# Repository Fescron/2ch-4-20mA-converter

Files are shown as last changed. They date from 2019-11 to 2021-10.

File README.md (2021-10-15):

# 2ch-4-20mA-converter






<br/>

This board converts two *4 - 20 mA* signals to a voltage using a `LMP8640` *Current Shunt Monitor* from *Texas Instruments*. To provide power to the *4 - 20 mA* sensors a `TEC2-0913` 2W 15V Isolated DC-DC converter is used from *Traco Power*. Quick-connect terminals from *Phoenix Contact* are also used.

To allow for extensive testing three separate GND nets/planes and a lot of test points are used. They can be connected together using jumpers if necessary. The power supply can also be disabled and fully disconnected from the sensors using a jumper as well (wich can also be used to measure the in-line current given to the whole sensor circuit).

- Click [here](hardware/2ch-4-20mA/2ch-4-20mA.pdf) to go to the **schematic**.

<br/>

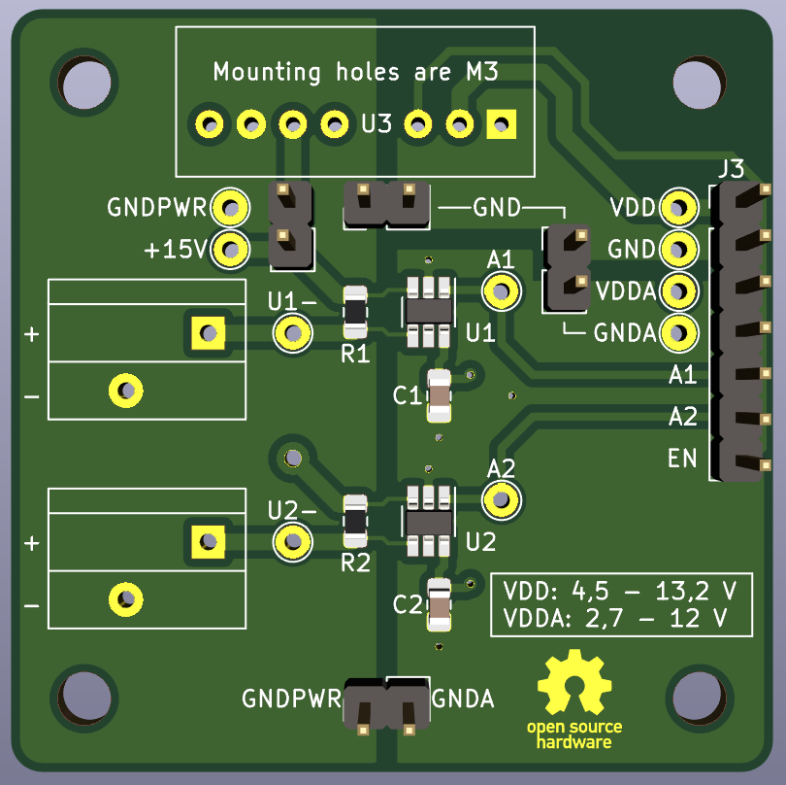
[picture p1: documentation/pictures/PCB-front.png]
PCB front
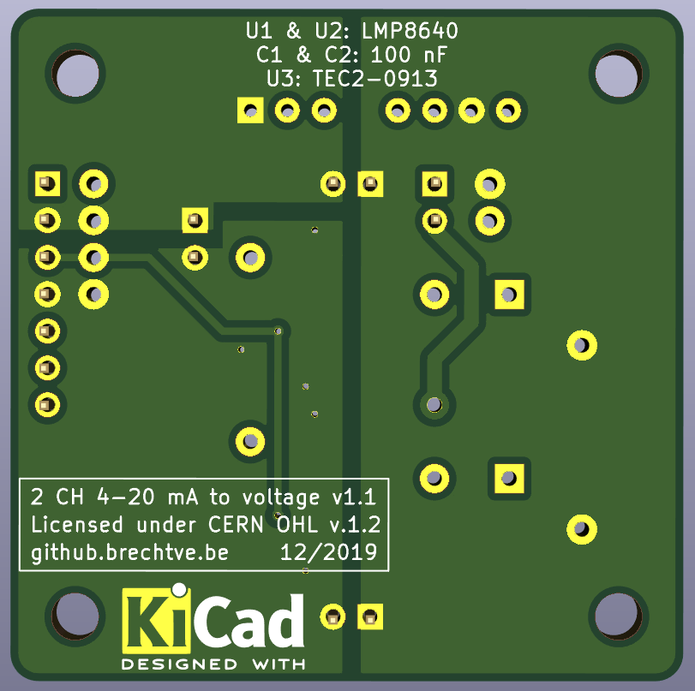
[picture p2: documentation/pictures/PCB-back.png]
PCB back
 &nbsp; &nbsp; &nbsp; &nbsp; &nbsp; 

<br/>

## LMP8640 vs INA196

A lot of designs still use the `INA196` *Current Shunt Monitor* from *Texas Instruments*. In the picture below is a comparison between the `LMP8640` and the `INA196`. No real disadvantage was found to not use the `LMP8640`.

<br/>

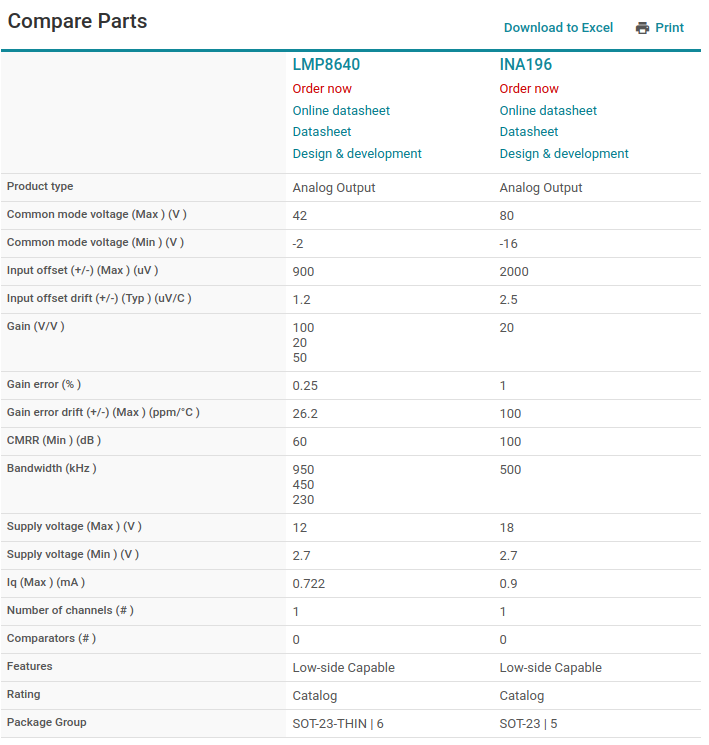
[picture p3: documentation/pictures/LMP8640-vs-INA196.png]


<br/>

## BOM

| Component | Value | Footprint | Other | Ordering |
| --- | --- | --- | --- | --- |
| U1, U2 | LMP8640 | SOT-23-Thin-6 | Texas Instruments Current Shunt Monitor | [Mouser.be](https://www.mouser.be/ProductDetail/Texas-Instruments/LMP8640MK-T-NOPB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) |
| U3 | TEC2-0913 | SIP-8 | Traco Power 2W 15V Isolated DC-DC converter | [Mouser.be](https://www.mouser.be/ProductDetail/TRACO-Power/TEC-2-0913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) |
| C1, C2 | 100 nF = 0,1 µF | 0805 | X7R, 16V, 10% | [Mouser.be](https://www.mouser.be/ProductDetail/Yageo/CC0805KRX7R7BB104?qs=sGAEpiMZZMs0AnBnWHyRQMMzfhmH8IQX2eB5GrOHrwc%3D) |
| R1, R2 | 6,2 Ω | 0805 | 0,1% | [Mouser.be](https://www.mouser.be/ProductDetail/TE-Connectivity-Neohm/CPF0805B6R2E1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) |
| R1, R2 (alt) | 4,99 Ω | 0805 | 0,1% | [Mouser.be](https://www.mouser.be/ProductDetail/TE-Connectivity-Neohm/CPF0805B4R99E1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) |
| J1, J2 | PTSA_1,5/_2-3,5-Z_BK | Pitch: 3,5 mm | 2 contacts @ 45° (20-16 AWG), 250V 2A | [Mouser.be](https://www.mouser.be/ProductDetail/Phoenix-Contact/1751765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) |

<br/>

## UPDATE 03/2020 - 1 CH board without power supply

To better conduct tests with the `LMP8640` chip a simple 1-CH board was layed out without a power supply and etched on a single sided board.

- Click [here](hardware/1ch-4-20mA/Plots/1ch-4-20mA.pdf) to go to the **schematic**.
- Click [here](hardware/1ch-4-20mA/Plots/1ch-4-20mA-F_Cu.pdf) to go to the **board layout** (mirrored).

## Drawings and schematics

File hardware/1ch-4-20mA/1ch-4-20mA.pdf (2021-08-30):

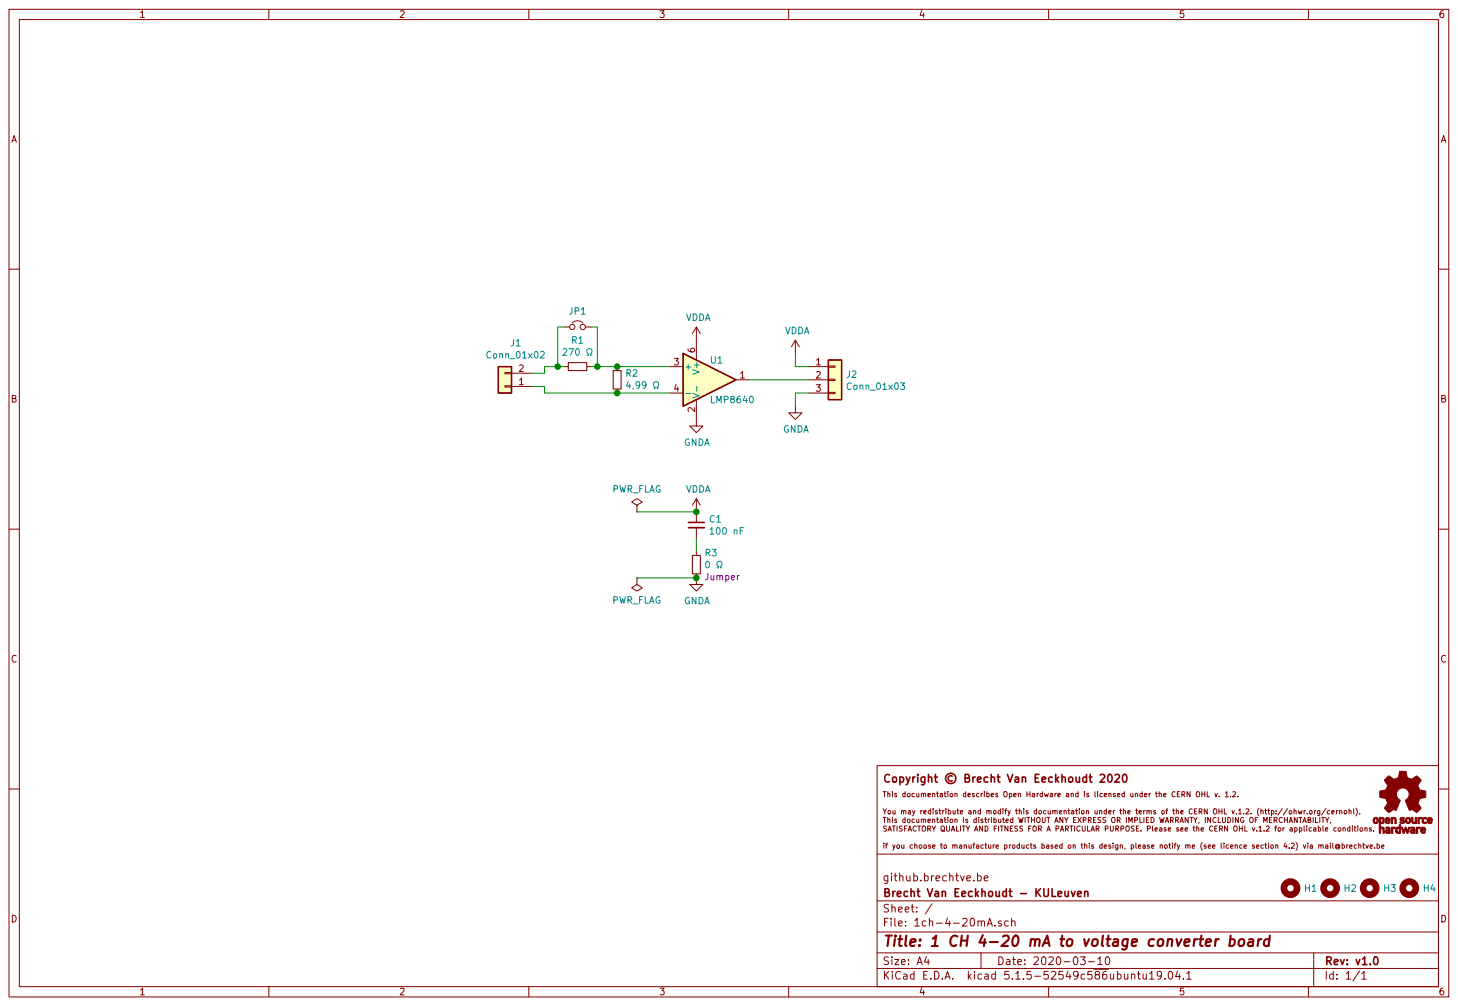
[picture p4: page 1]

Copyright © Brecht Van Eeckhoudt 2020

This documentation describes Open Hardware and is licensed under the CERN OHL v. 1.2.

You may redistribute and modify this documentation under the terms of the CERN OHL v.1.2. (http://ohwr.org/cernohl).

if you choose to manufacture products based on this design, please notify me (see licence section 4.2) via mail@brechtve.be H2

github.brechtve.be
File: 1ch-4-20mA.sch Sheet: / Brecht Van Eeckhoudt - KULeuven

Id: 1/1 Title: 1 CH 4-20 mA to voltage converter board

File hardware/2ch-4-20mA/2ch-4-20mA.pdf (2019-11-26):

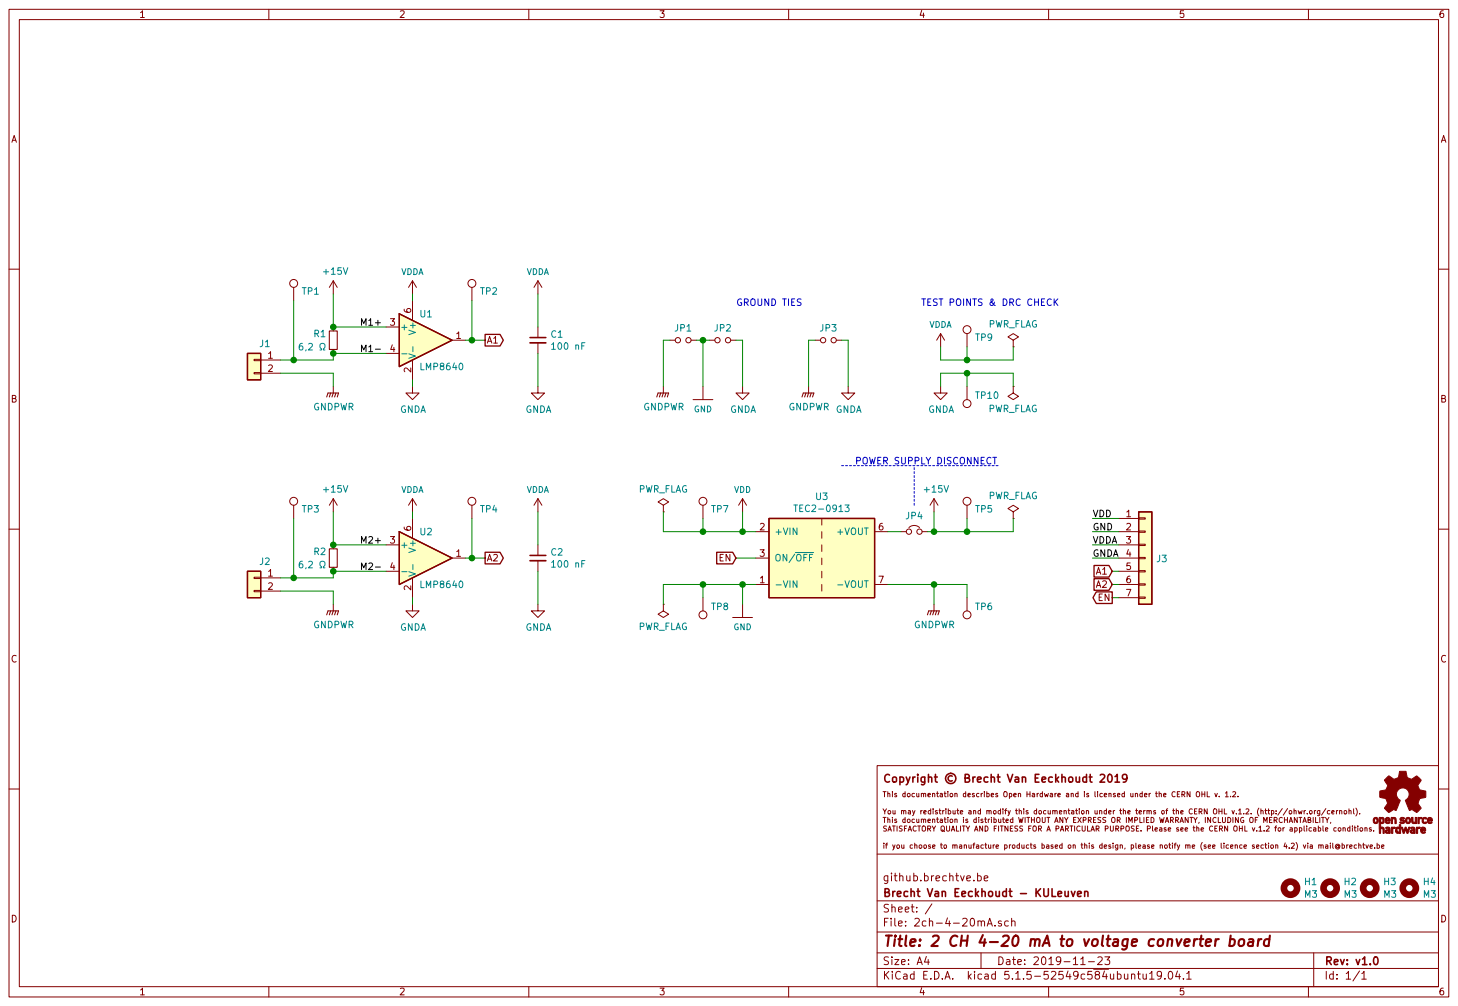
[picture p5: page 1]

TEST POINTS & DRC CHECK

Copyright © Brecht Van Eeckhoudt 2019

This documentation describes Open Hardware and is licensed under the CERN OHL v. 1.2.

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

github.brechtve.be
File: 2ch-4-20mA.sch Sheet: / Brecht Van Eeckhoudt - KULeuven

Id: 1/1 Title: 2 CH 4-20 mA to voltage converter board

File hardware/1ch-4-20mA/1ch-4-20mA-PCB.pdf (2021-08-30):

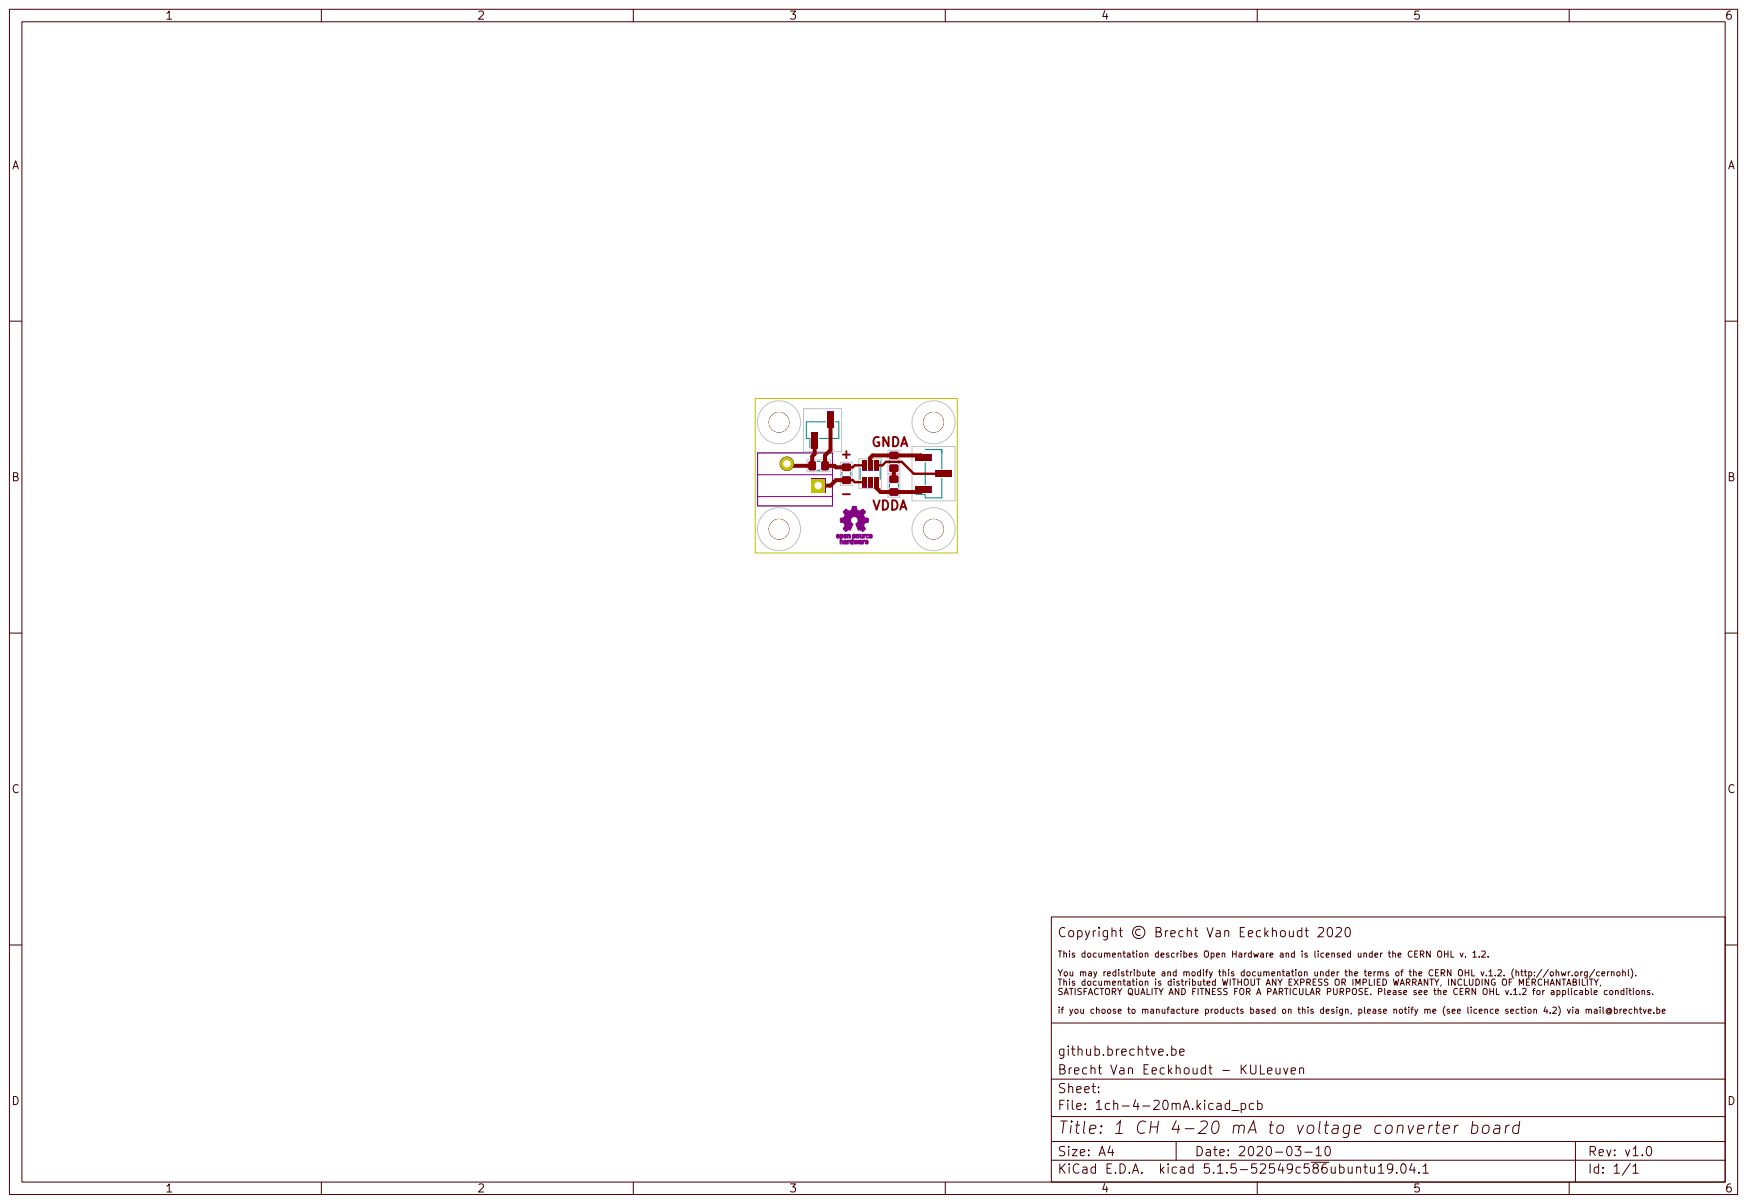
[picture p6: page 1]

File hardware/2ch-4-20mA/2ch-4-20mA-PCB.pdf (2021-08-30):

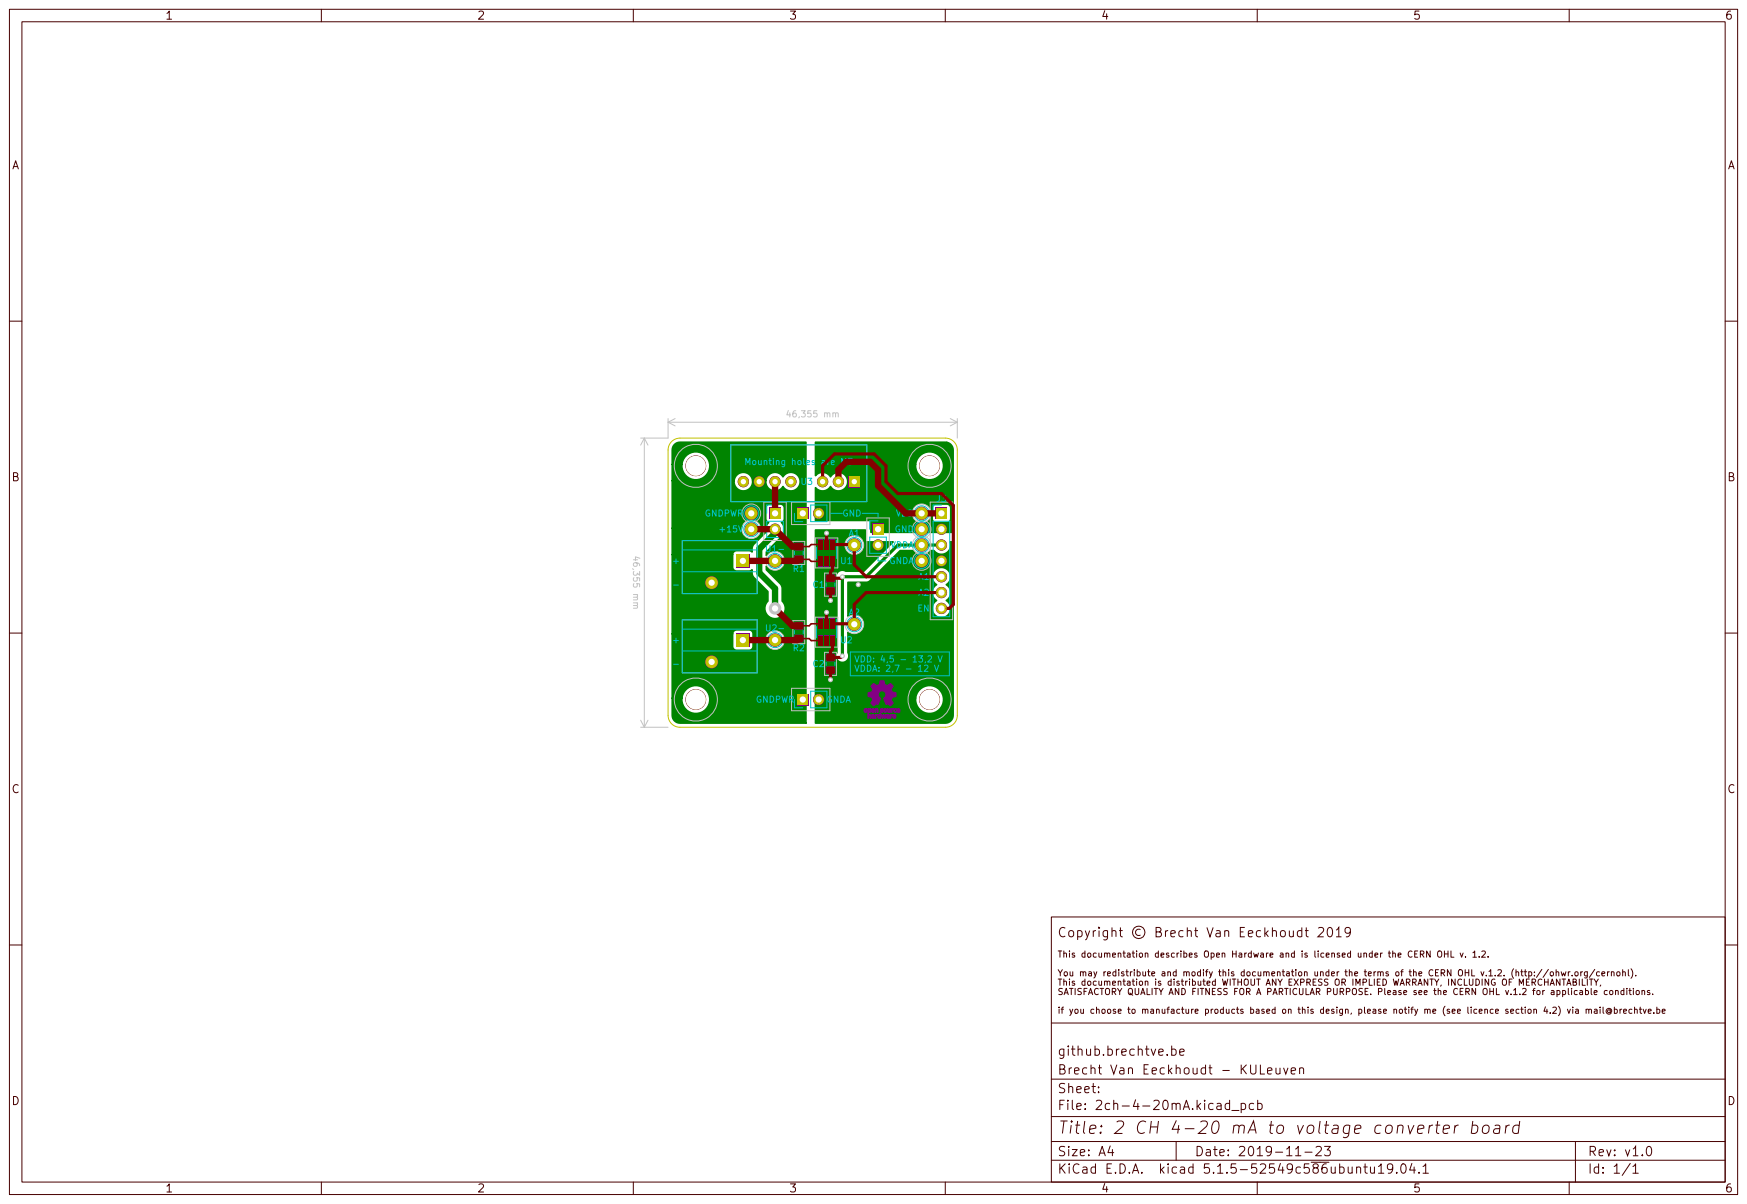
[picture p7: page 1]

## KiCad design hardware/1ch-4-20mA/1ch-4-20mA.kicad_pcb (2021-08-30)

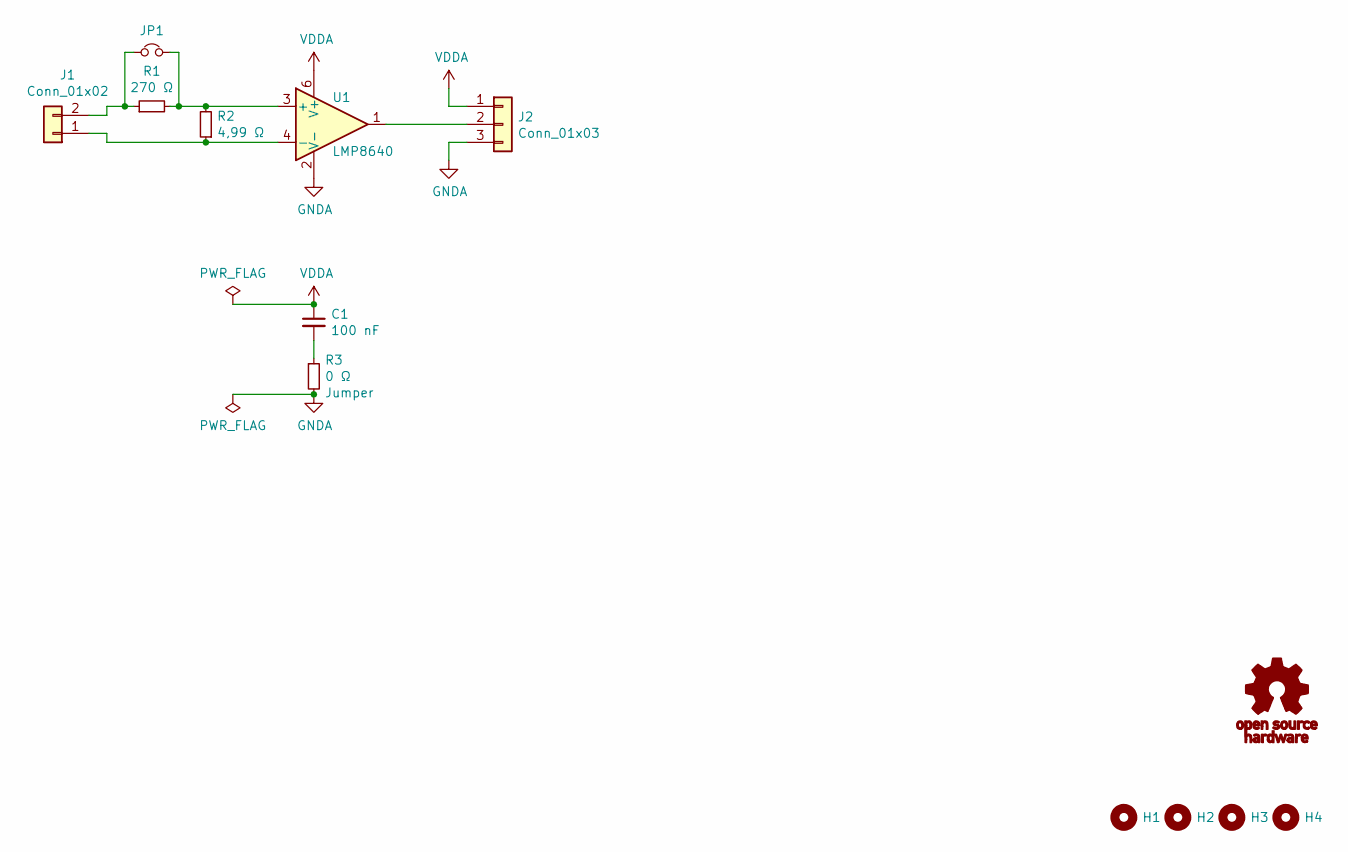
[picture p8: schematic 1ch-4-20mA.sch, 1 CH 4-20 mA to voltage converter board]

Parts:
C1: 100 nF; C_0805_2012Metric_Pad1.15x1.40mm_HandSolder
G1: Symbol_OSHW-Logo_11.4x12mm; OSHW-Logo_5.7x6mm_SolderMask
H1, H2, H3, H4: MountingHole; MountingHole_3.2mm_M3
J1: Conn_01x02; PhoenixContact_PTSA_1,5_2-G-3,5_1x02_P3.50mm_Angled
J2: Conn_01x03; PinHeader_1x03_P2.54mm_Vertical_SMD_Pin1Right
JP1: Jumper_NC_Small; PinHeader_1x02_P2.54mm_Vertical_SMD_Pin1Left
R1: 270 Ω; R_0805_2012Metric_Pad1.15x1.40mm_HandSolder
R2: 4,99 Ω; R_0805_2012Metric_Pad1.15x1.40mm_HandSolder
R3: 0 Ω; R_0805_2012Metric_Pad1.15x1.40mm_HandSolder
U1: LMP8640; SOT-23-6_Handsoldering

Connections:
GNDA: J2.3, R3.2, U1.2 (V-)
unnamed: C1.2, R3.1
unnamed: J1.1, R2.1, U1.4 (-)
unnamed: J1.2, JP1.1, R1.1
unnamed: J2.2, U1.1
unnamed: JP1.2, R1.2, R2.2, U1.3 (+)
VDDA: C1.1, J2.1, U1.6 (V+)

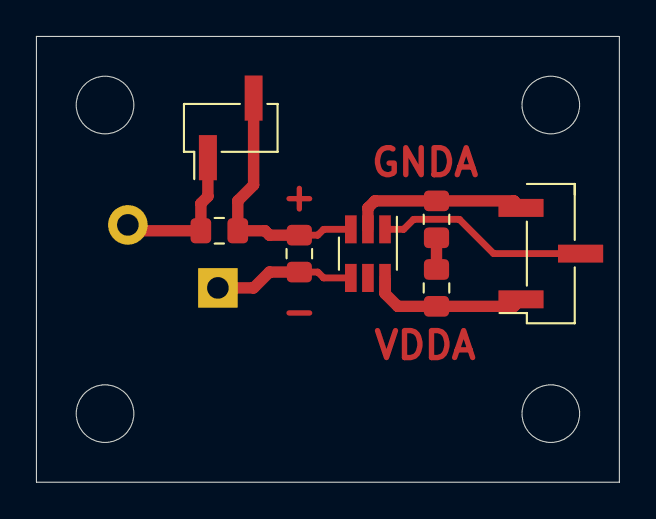
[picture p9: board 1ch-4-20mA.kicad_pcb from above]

Board: 2 copper layers, 32.4 x 24.8 mm, 13 parts (1 on the bottom side), 7 nets.

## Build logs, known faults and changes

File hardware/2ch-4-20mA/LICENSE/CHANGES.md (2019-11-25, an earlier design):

# Modifications made by Licensee (see section 3.4.b)

## Extract from license

**3.4.** The Licensee may communicate to the public and distribute the modified Documentation (thereby in addition to being a Licensee also becoming a Licensor), always provided that he shall:

- **a)** comply with section 3.1;
- **b)** cause the modified Documentation to carry prominent notices stating that the Licensee has modified the Documentation, with the date and description of the modifications;
- **c)** cause the modified Documentation to carry a new Documentation Location notice if the original Documentation provided for one;
- **d)** make available the modified Documentation at the same level of abstraction as that of the Documentation, in the preferred format for making modifications to it (e.g. the native format of the CAD tool as applicable), and in the event that format is proprietary, in a format viewable with a tool licensed under an OSI-approved license if the proprietary tool can create it; and
- **e)** license the modified Documentation under the terms and conditions of this Licence or, where applicable, a later version of this Licence as may be issued by CERN.

<br/>

## Versions

- v1.0: Initial version (Brecht Van Eeckhoudt - 24/11/2019)

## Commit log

2019-11-25 Updated schematic with selectable text
2019-11-26 Updated PCB with new OSHW logo
    [2ch-4-20mA-B_Cu.gbl, 2ch-4-20mA-B_Mask.gbs, 2ch-4-20mA-B_Paste.gbp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]
2019-12-03 Updated readme with note about wrong footprint
2019-12-10 Updated header footprint
    [2ch-4-20mA-B_Cu.gbl, 2ch-4-20mA-B_Mask.gbs, 2ch-4-20mA-B_Paste.gbp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]
2020-01-07 Updated BOM with correct gain for current shunt monitor
2020-03-16 Added info about 1CH board
2020-03-16 Added 1CH single layer breakout board
    [1ch-4-20mA.kicad_pcb, 1ch-4-20mA.sch]
2021-08-30 Small info changes
    [1ch-4-20mA.kicad_pcb, 1ch-4-20mA.sch]

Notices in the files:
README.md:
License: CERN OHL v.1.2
